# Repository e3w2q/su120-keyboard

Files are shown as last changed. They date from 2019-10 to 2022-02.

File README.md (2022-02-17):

# SU120





Expandable keyboard PCB with up to 120 keys.
main image

## What is the SU120?

The SU120 is an assemblable and expandable keyboard PCB with biscuits, screws and wire.

I use JIS Kana input method, but at that time I couldn't find  split JIS keyboard PCBs.

So I designed the PCB to make the keyboard layout easy to trial and error.

You may make Row-Staggered, Column-Staggerd, Ortholinear, or other layouts keyboard.

SU is Japanese homophones: 州(sandbank) and 鬆(porous).

## Why open source?

Anyone interested in keyboard could try the keyboard layout more easily.

## Link

[Hardware data (PCB)](/pcb/)

[Plate data (PCB)](/plate-pcb/)

[PCB Order Guide](https://github.com/e3w2q/su120-keyboard-doc/blob/master/common/pcb_order_guide.md) / [PCBの入手方法](https://github.com/e3w2q/su120-keyboard-doc/blob/master/common/pcb_order_guide_jp.md)

[Firmware](https://github.com/e3w2q/qmk_firmware/tree/e3w2q/keyboards/e3w2q/su120)

[Remap/VIA Firmware Hex File](/firmware/)

[How to create a custom layout](https://github.com/e3w2q/su120-keyboard-doc/blob/master/custom-layout/readme.md) / [自由なレイアウトを作成するには](https://github.com/e3w2q/su120-keyboard-doc/blob/master/custom-layout/readme_jp.md)

## Example

### 15 Key (+2 Knob) Keypad



[ビルドガイド](https://github.com/e3w2q/su120-keyboard-doc/blob/master/sasami17/readme_jp.md)

### 30 Key Ortholinear Keyboard



[ビルドガイド](https://github.com/e3w2q/su120-keyboard-doc/blob/master/sasami30/readme_jp.md)

### 120 Key Split Ortholinear Keyboard 



[ビルドガイド](https://github.com/e3w2q/su120-keyboard-doc/blob/master/momo120/readme_jp.md)

### 40% Row-Staggered Keyboard



[Photos / ギャラリー](https://github.com/e3w2q/su120-keyboard-doc/blob/master/negima43/readme.md)

### 5% Keyboard



[Photos / ギャラリー](https://github.com/e3w2q/su120-keyboard-doc/blob/master/negima5/readme.md)

### Badge and Clip



[ビルドガイド](https://github.com/e3w2q/su120-keyboard-doc/blob/master/badge_and_clip/readme_jp.md)

### 55% Split Ortholinear Keyboard by [ryuichio](https://twitter.com/ryuichio1)





### [ELEPHANT42](https://twitter.com/hashtag/elephant42?src=hash) Prototype by [🐰](https://twitter.com/illness072)





### Pigeon44 by [🐰](https://twitter.com/illness072)





### 18 Key 2 Knob Low-profile Keypad by [🐰](https://twitter.com/illness072)



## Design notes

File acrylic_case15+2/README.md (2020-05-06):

# 15 Key 2 Rotary Encoder Macropad Acrylic Case Data
Acrylic thickness: 2mm
## Kicad Layout
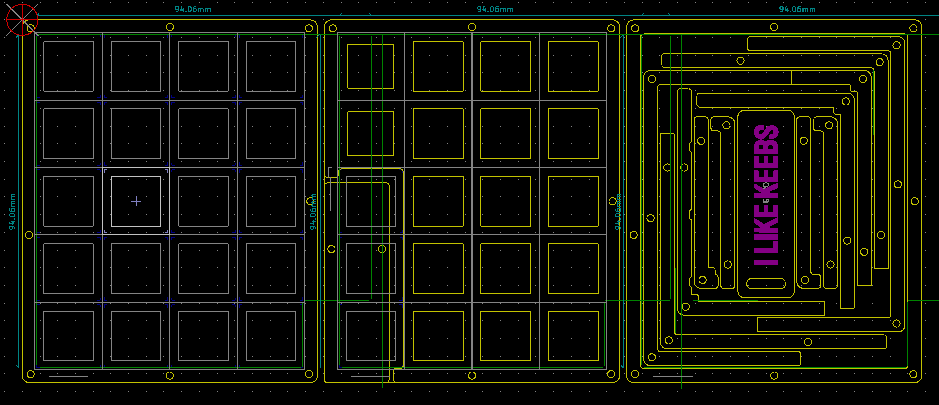
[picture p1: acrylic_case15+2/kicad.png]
Kicad Layout

## SVG
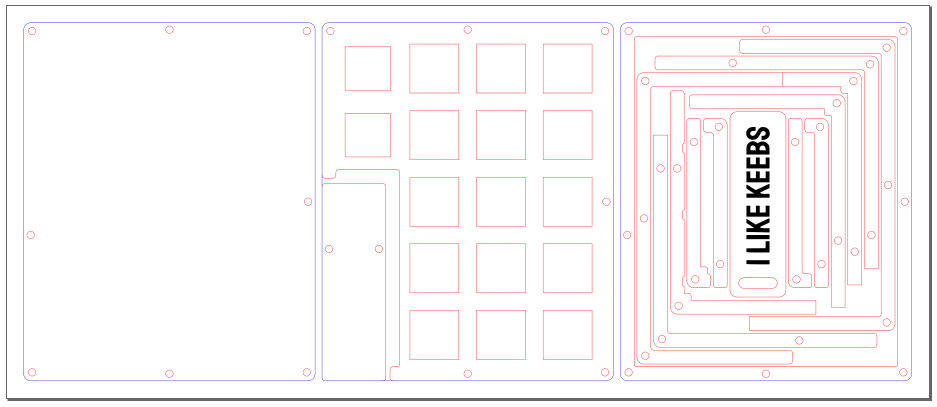
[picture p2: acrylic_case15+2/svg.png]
SVG


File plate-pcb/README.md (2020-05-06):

# SU120 Plate Data

## PCB Layout
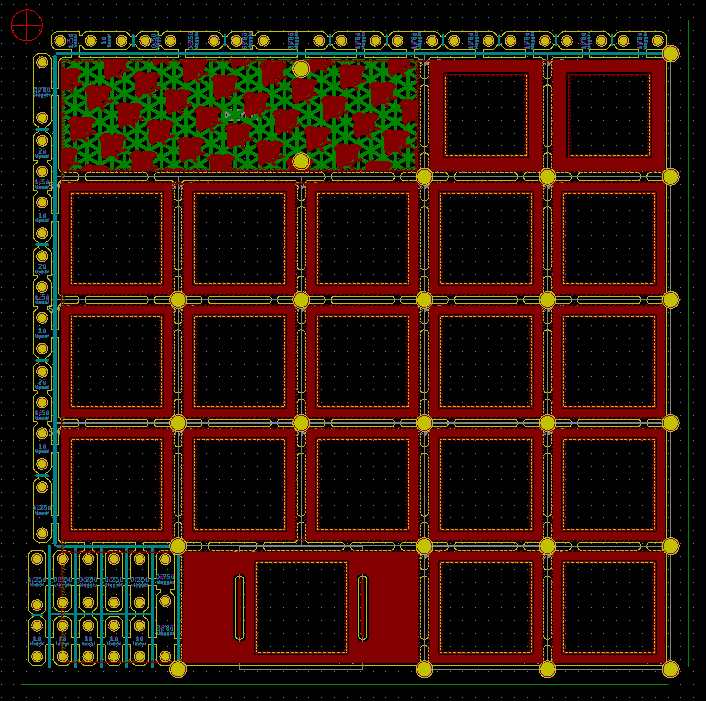
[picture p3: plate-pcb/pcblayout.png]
PCB Layout


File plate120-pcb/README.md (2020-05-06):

# 120 Key Split Ortholinear Keyboard Plate Data

## 3D View
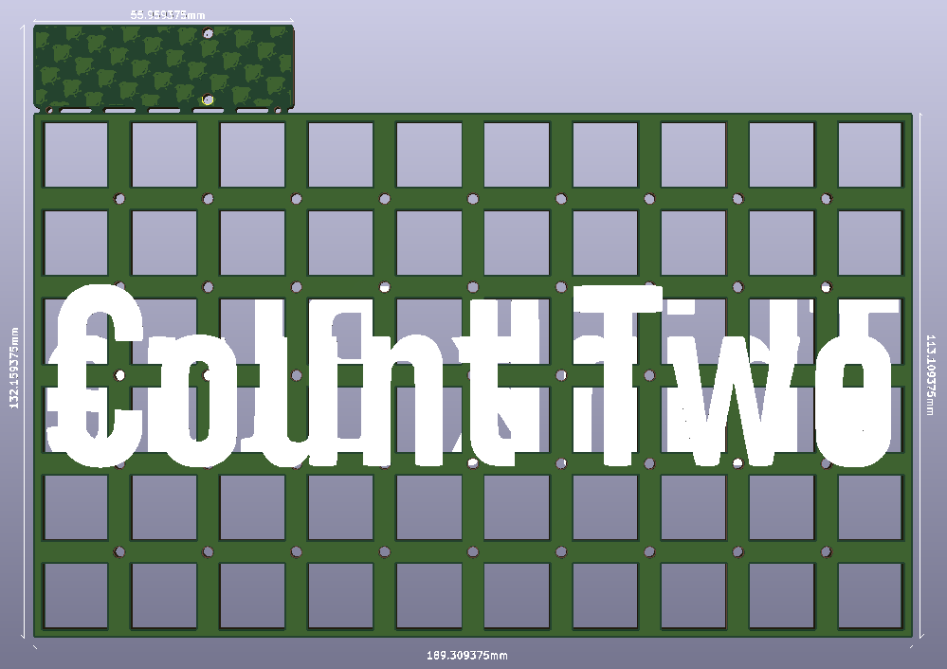
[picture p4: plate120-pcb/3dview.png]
3dview


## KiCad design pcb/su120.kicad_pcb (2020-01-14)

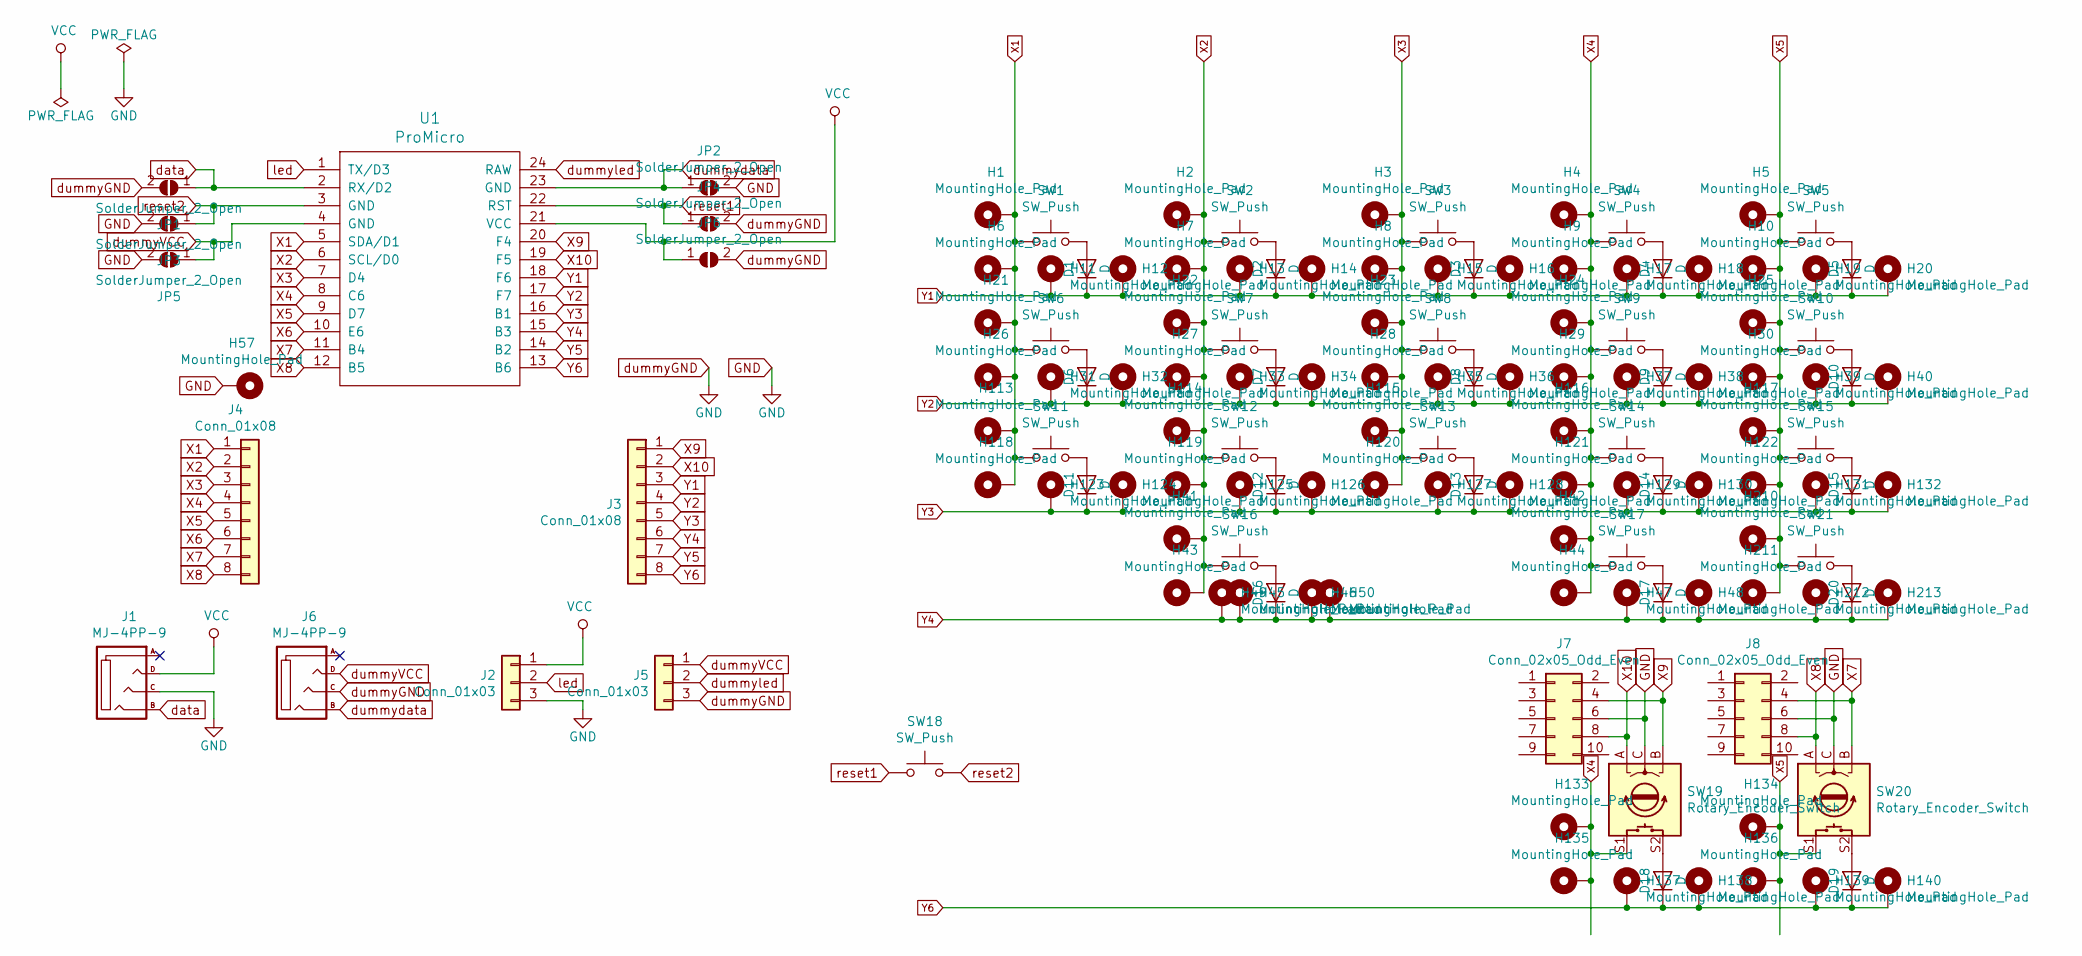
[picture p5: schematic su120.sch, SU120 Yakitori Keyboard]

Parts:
D1, D2, D3, D4, D5, D6, D7, D8, D9, D10, D11, D12, D13, D14, D15, D16, D17, D18, D19, D20: D; diode_TH_SMD_rev2
H1, H2, H3, H4, H5, H6, H7, H8, H9, H10, H11, H12, H13, H14, H15, H16, H17, H18, H19, H20, H21, H22, H23, H24, H25, H26, H27, H28, H29, H30, H31, H32, H33, H34, H35, H36, H37, H38, H39, H40, H41, H42, H43, H44, H45, H46, H47, H48, H49, H50, H57, H113, H114, H115, H116, H117, H118, H119, H120, H121, H122, H123, H124, H125, H126, H127, H128, H129, H130, H131, H132, H133, H134, H135, H136, H137, H138, H139, H140, H210, H211, H212, H213: MountingHole_Pad; 1pin_conn
J1, J6: MJ-4PP-9
J2, J5: Conn_01x03; StripLED_rev2
J3, J4: Conn_01x08; PinHeader_1x08_P2.54mm_Vertical_rev2
J7, J8: Conn_02x05_Odd_Even; IDC-Header_2x05_P2.54mm_Vertical
JP1, JP2, JP3, JP4, JP5, JP6: SolderJumper_2_Open; SolderJumper-2_P1.3mm_Open_Pad1.0x1.0mm
SW1, SW2, SW3, SW4, SW5, SW6, SW7, SW8, SW9, SW10, SW11, SW12, SW13, SW14, SW15, SW16, SW17, SW21: SW_Push; CherryMX_MidHeight_Choc_Hotswap_rev5
SW18: SW_Push; ResetSW
SW19, SW20: Rotary_Encoder_Switch; RotaryEncoder_Alps_EC11E-Switch_Vertical_H20mm_rev2
U1: ProMicro; ArduinoProMicro-ZigZag_rev5

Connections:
GND: H57.1, J1.C, J2.3, J5.3, J6.C, J7.6, J8.6, JP1.2 (B), JP2.2 (B), JP3.2 (B), JP4.2 (B), JP5.2 (B), JP6.2 (B), SW19.C, SW20.C
unnamed: D1.2 (A), SW1.2
unnamed: D2.2 (A), SW2.2
unnamed: D3.2 (A), SW3.2
unnamed: D4.2 (A), SW4.2
unnamed: D5.2 (A), SW5.2
unnamed: D6.2 (A), SW6.2
unnamed: D7.2 (A), SW7.2
unnamed: D8.2 (A), SW8.2
unnamed: D9.2 (A), SW9.2
unnamed: D10.2 (A), SW10.2
unnamed: D11.2 (A), SW11.2
unnamed: D12.2 (A), SW12.2
unnamed: D13.2 (A), SW13.2
unnamed: D14.2 (A), SW14.2
unnamed: D15.2 (A), SW15.2
unnamed: D16.2 (A), SW16.2
unnamed: D17.2 (A), SW17.2
unnamed: D18.2 (A), SW19.S2
unnamed: D19.2 (A), SW20.S2
unnamed: D20.2 (A), SW21.2
VCC: J1.D, J2.1, JP6.1 (A), U1.21 (VCC)
X1: H1.1, H6.1, H21.1, H26.1, H113.1, H118.1, J4.1, SW1.1, SW6.1, SW11.1, U1.5 (SDA/D1)
X2: H2.1, H7.1, H22.1, H27.1, H41.1, H43.1, H114.1, H119.1, J4.2, SW2.1, SW7.1, SW12.1, SW16.1, U1.6 (SCL/D0)
X3: H3.1, H8.1, H23.1, H28.1, H115.1, H120.1, J4.3, SW3.1, SW8.1, SW13.1, U1.7 (D4)
X4: H4.1, H9.1, H24.1, H29.1, H42.1, H44.1, H116.1, H121.1, H133.1, H135.1, J4.4, SW4.1, SW9.1, SW14.1, SW17.1, SW19.S1, U1.8 (C6)
X5: H5.1, H10.1, H25.1, H30.1, H117.1, H122.1, H134.1, H136.1, H210.1, H211.1, J4.5, SW5.1, SW10.1, SW15.1, SW20.S1, SW21.1, U1.9 (D7)
X6: J4.6, U1.10 (E6)
X7: J4.7, J8.4, SW20.B, U1.11 (B4)
X8: J4.8, J8.8, SW20.A, U1.12 (B5)
X9: J3.1, J7.4, SW19.B, U1.20 (F4)
X10: J3.2, J7.8, SW19.A, U1.19 (F5)
Y1: D1.1 (K), D2.1 (K), D3.1 (K), D4.1 (K), D5.1 (K), H11.1, H12.1, H13.1, H14.1, H15.1, H16.1, H17.1, H18.1, H19.1, H20.1, J3.3, U1.18 (F6)
Y2: D6.1 (K), D7.1 (K), D8.1 (K), D9.1 (K), D10.1 (K), H31.1, H32.1, H33.1, H34.1, H35.1, H36.1, H37.1, H38.1, H39.1, H40.1, J3.4, U1.17 (F7)
Y3: D11.1 (K), D12.1 (K), D13.1 (K), D14.1 (K), D15.1 (K), H123.1, H124.1, H125.1, H126.1, H127.1, H128.1, H129.1, H130.1, H131.1, H132.1, J3.5, U1.16 (B1)
Y4: D16.1 (K), D17.1 (K), D20.1 (K), H45.1, H46.1, H47.1, H48.1, H49.1, H50.1, H212.1, H213.1, J3.6, U1.15 (B3)
Y5: J3.7, U1.14 (B2)
Y6: D18.1 (K), D19.1 (K), H137.1, H138.1, H139.1, H140.1, J3.8, U1.13 (B6)
data: J1.B, JP1.1 (A), U1.2 (RX/D2)
dummyVCC: J5.1, J6.D, JP5.1 (A), U1.4 (GND)
dummydata: J6.B, JP2.1 (A), U1.23 (GND)
dummyled: J5.2, U1.24 (RAW)
led: J2.2, U1.1 (TX/D3)
reset1: JP4.1 (A), SW18.1, U1.22 (RST)
reset2: JP3.1 (A), SW18.2, U1.3 (GND)

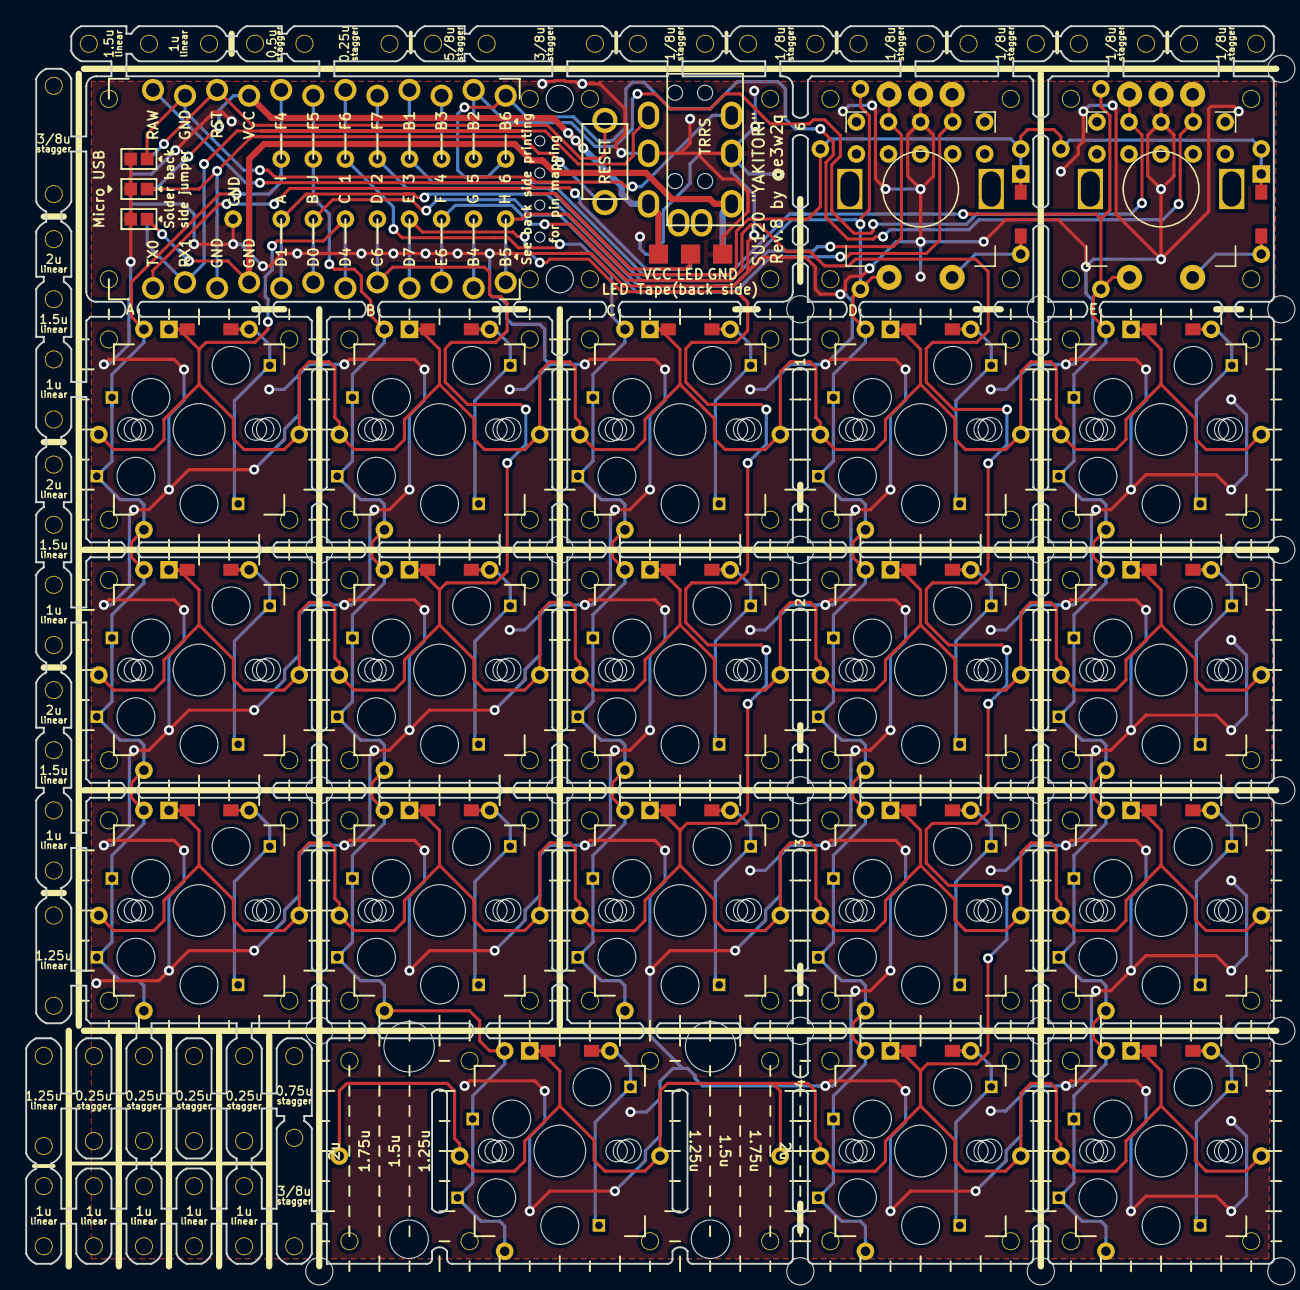
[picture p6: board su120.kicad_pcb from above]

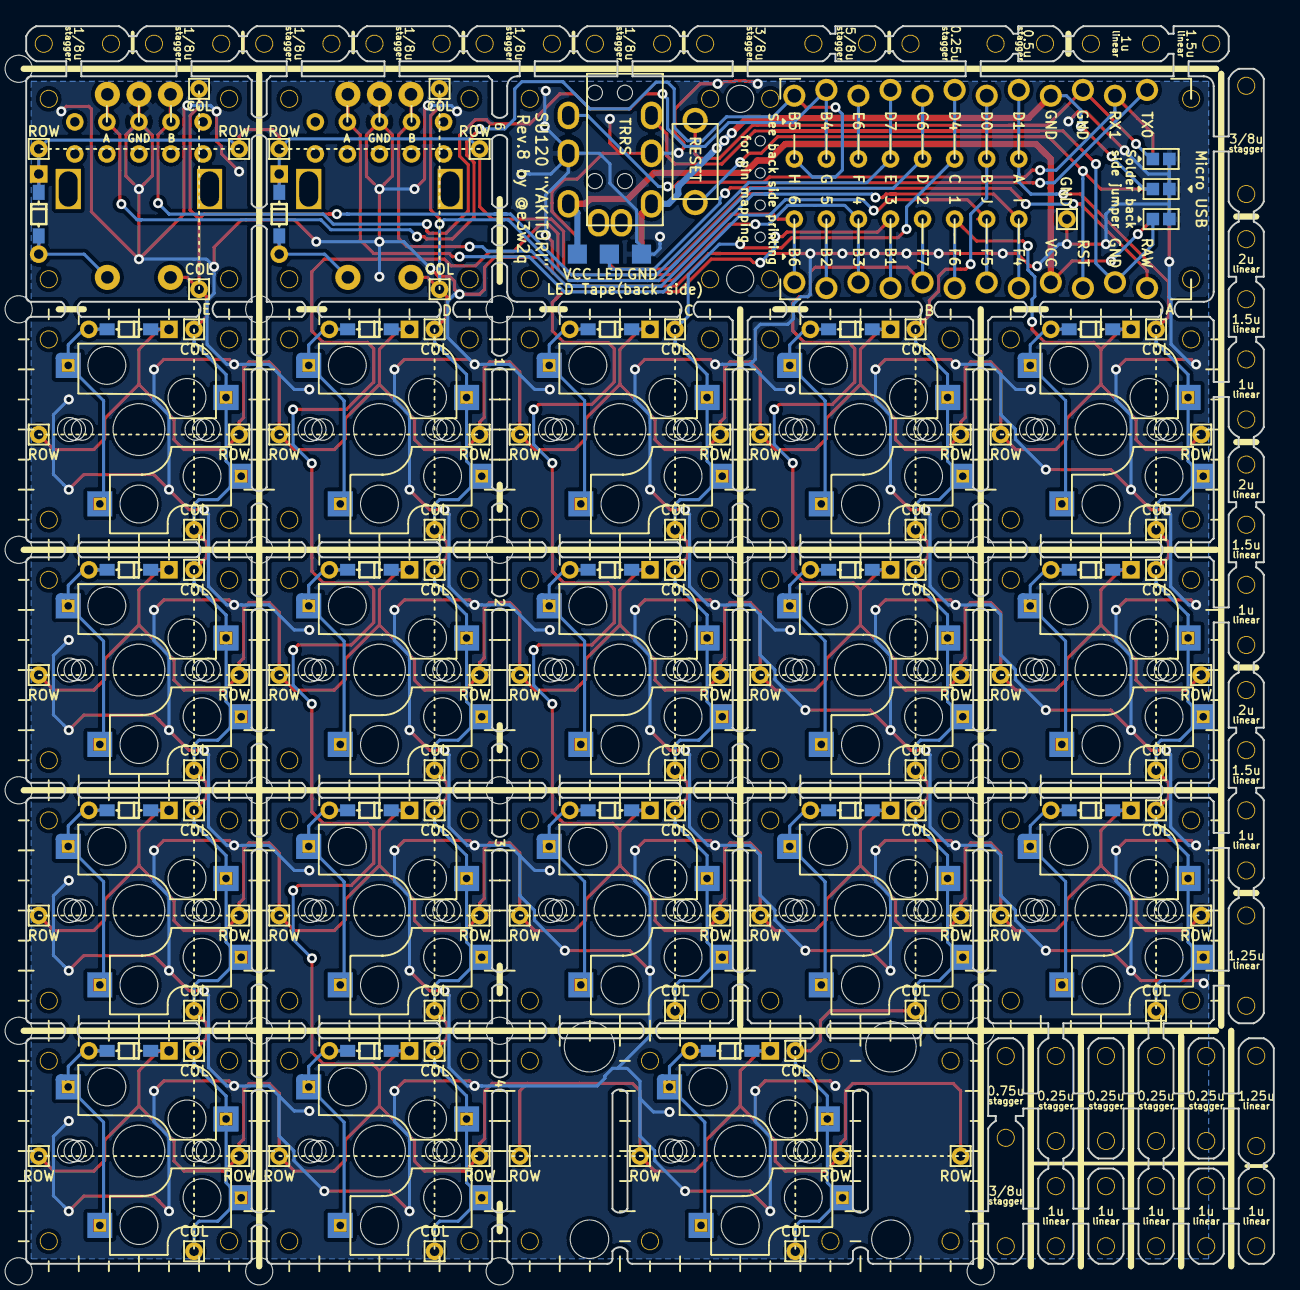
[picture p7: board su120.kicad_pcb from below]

Board: 2 copper layers, 98.8 x 98.0 mm, 139 parts (6 on the bottom side), 45 nets.

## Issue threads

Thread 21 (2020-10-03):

question regarding switch support

rustysys-dev, 2020-10-03:
does this project support Kailh Choc v2 switches? or only v1?

JellyTitan, 2022-10-13:
No, it only supports Choc v1.

I don't think the V2 switches ever really caught on - to the point that there is no hotswap socket available for them. If it's cherry keycaps you're after, there's tons of choc adapters. If it's the low travel your after, Kailh, and Akko both have speed switches with a 1.1 mm actuation distance - which is actually lower than the choc v2.

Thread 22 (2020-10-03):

led support

rustysys-dev, 2020-10-03:
Does the PCB support adding leds?

JellyTitan, 2022-10-13:
It does not. The individual pcbs have traces for rows and columns only.

The [MxLEDBitPCB](https://github.com/swanmatch/MxLEDBitPCB/blob/master/readme_en.md), however, is similar to the su120, and does support the delightful SK-6812 MINI-E. (The mini-e is way easier to solder than the standard sk6812).

The MxLEDBitPCB does not have biscuits or a sweet microprocessor socket like the su120 does, so the wiring will be a bit more complicated - you'll have to run wires from rows and columns to the microprocessor yourself.

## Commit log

2019-06-04 Add sample
2019-07-05 footprint add
2019-07-06 fix PCB
    [su120.kicad_pcb, su120.sch]
2019-09-16 Rotary Encoder's pin exchanged
    [su120.kicad_pcb, su120.sch]
2019-09-17 add plate PCB
    [su120-plate.kicad_pcb]
2019-11-24 update and add plate120-pcb
    [su120-plate120.kicad_pcb]
2020-01-14 adjust silk and hole size
    [su120.kicad_pcb]
2020-05-06 Add acrylic case data
    [su120-case15+2-draft.kicad_pcb, su120-case15+2.kicad_pcb]
2022-02-09 40% Column-Staggered → 40% Row-Staggered
    Negima43 is row-staggered, not columnar-staggered

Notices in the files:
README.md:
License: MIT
